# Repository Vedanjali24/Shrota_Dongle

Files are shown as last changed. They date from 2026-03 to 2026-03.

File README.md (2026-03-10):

# Shrota_Dongle
The Shrota Dongle is a custom-designed Ground Control Station (GCS) telemetry interface PCB developed as part of our rocketry team’s avionics and communication system. The board enables reliable reception and processing of real-time telemetry transmitted from the rocket during flight.

The system is built around an STM32 microcontroller, which manages telemetry data handling and communication with a LoRa RYLR module used for long-range wireless data reception. This allows the ground station to receive critical flight parameters and system status during launch and testing.

The PCB features a 5.5 V to 3.3 V regulated power architecture with VCC filtering to ensure stable operation of RF and digital components. High-speed and low-speed oscillators provide precise timing, while external SPI Flash memory allows telemetry data to be logged for redundancy and post-flight analysis.

Developed collaboratively as part of our team’s ground infrastructure, the Shrota Dongle provides a robust communication link for monitoring mission-critical rocket performance.





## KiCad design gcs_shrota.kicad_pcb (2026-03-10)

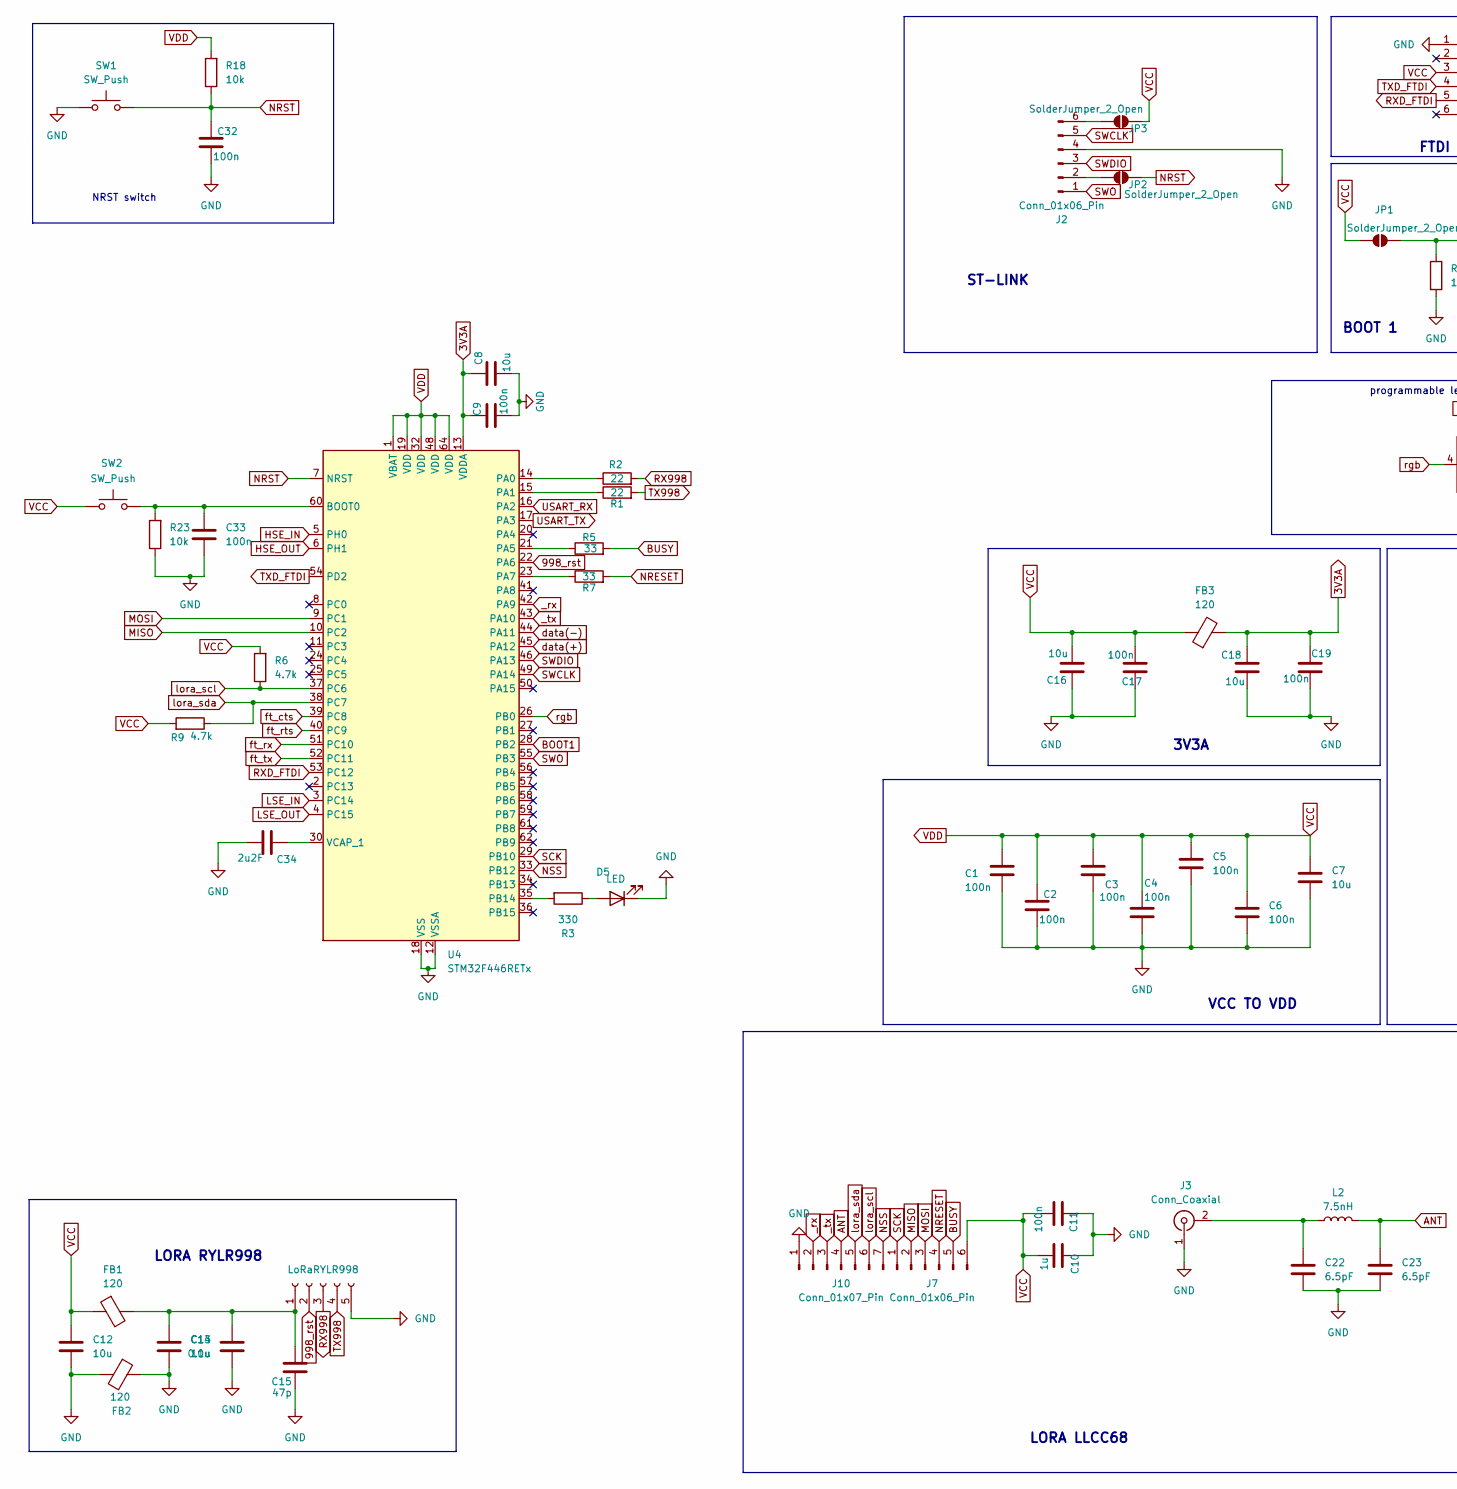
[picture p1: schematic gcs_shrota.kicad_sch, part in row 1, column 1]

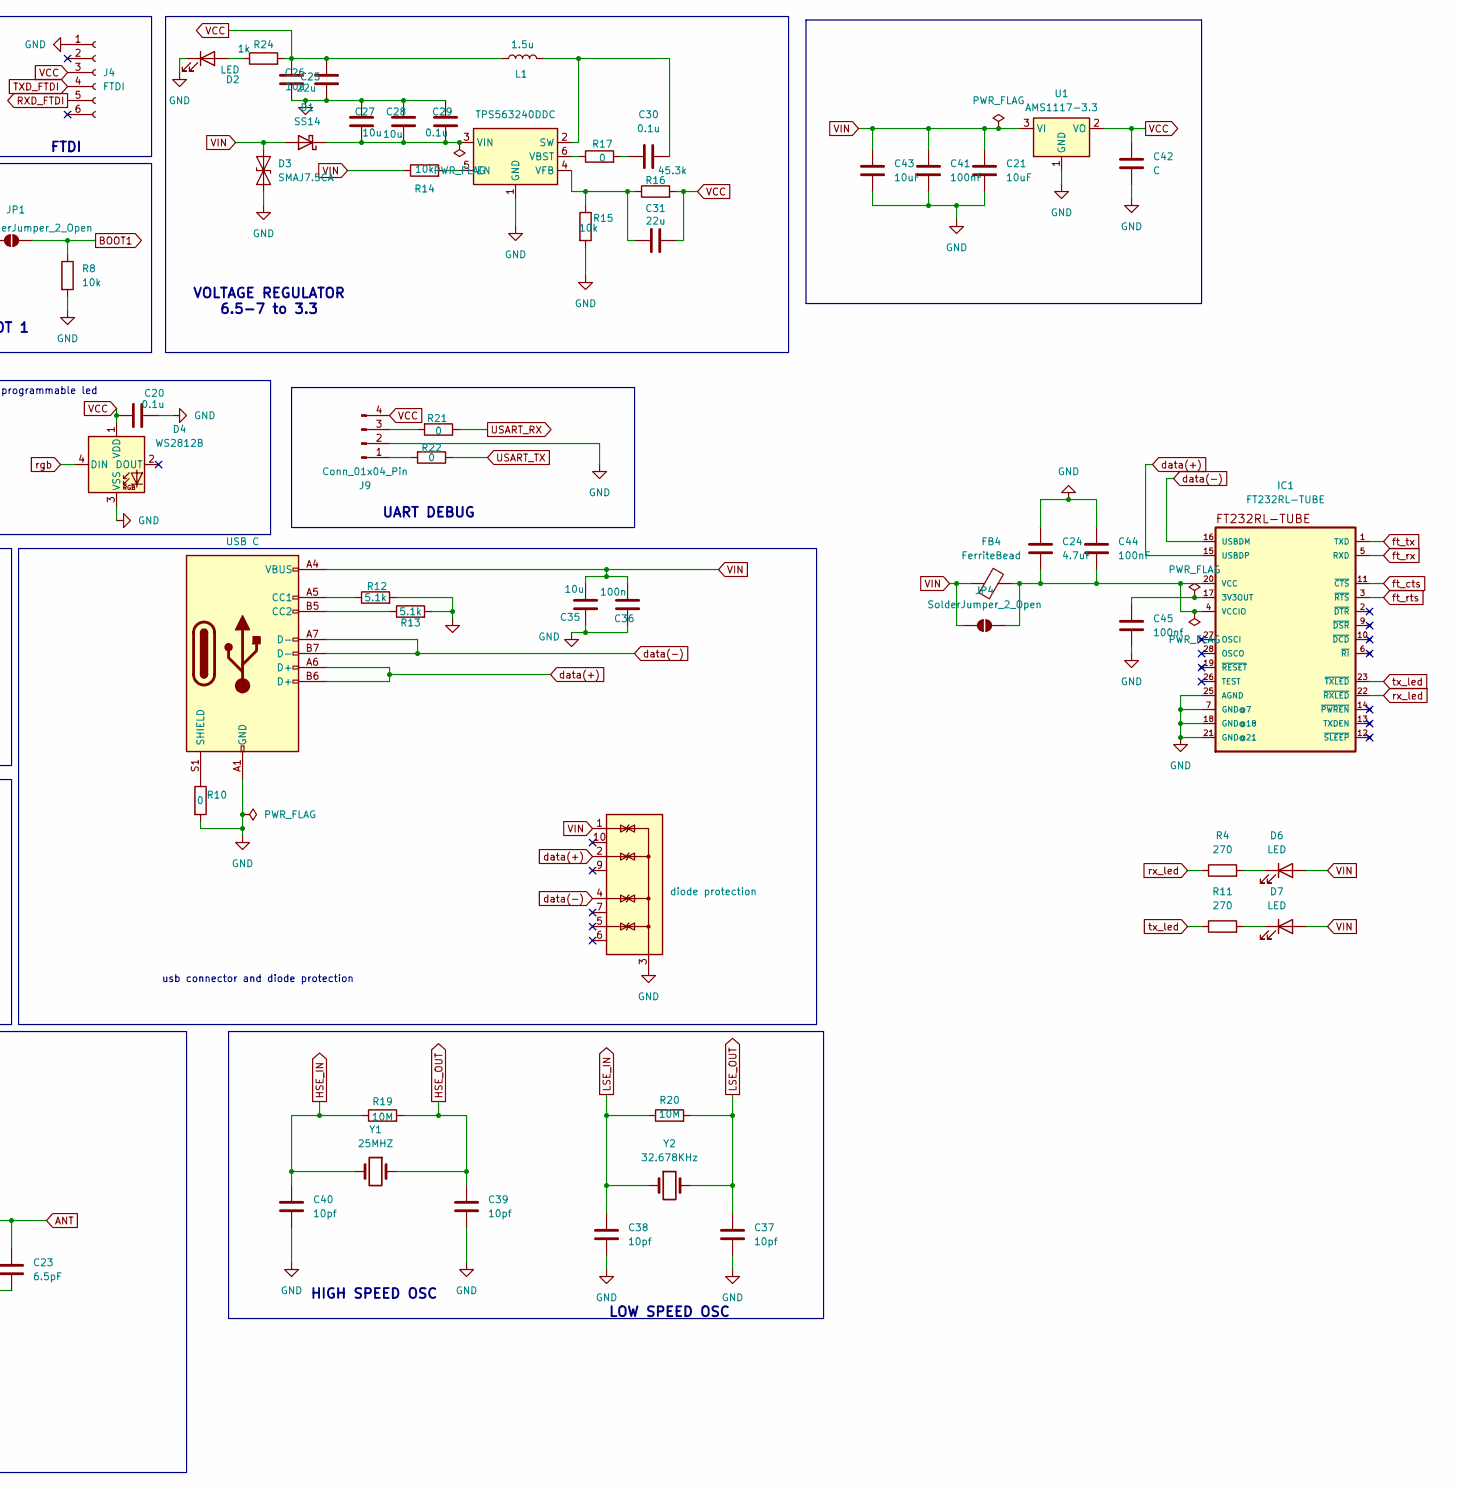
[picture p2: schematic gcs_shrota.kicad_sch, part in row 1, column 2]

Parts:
C1, C2, C3, C4, C5, C6, C9, C11, C17, C19, C32, C33, C36: 100n; C_0603_1608Metric_Pad1.08x0.95mm_HandSolder
C7, C8, C12, C13, C16, C18, C26, C27, C28, C35: 10u; C_0603_1608Metric_Pad1.08x0.95mm_HandSolder
C10: 1u; C_0603_1608Metric_Pad1.08x0.95mm_HandSolder
C14, C20, C29, C30: 0.1u; C_0603_1608Metric_Pad1.08x0.95mm_HandSolder
C15: 47p; C_0603_1608Metric_Pad1.08x0.95mm_HandSolder
C21, C43: 10uF; C_0603_1608Metric_Pad1.08x0.95mm_HandSolder
C22, C23: 6.5pF; C_0603_1608Metric_Pad1.08x0.95mm_HandSolder
C24: 4.7uF; C_0603_1608Metric_Pad1.08x0.95mm_HandSolder
C25, C31: 22u; C_0603_1608Metric_Pad1.08x0.95mm_HandSolder
C34: 2u2F; C_0603_1608Metric_Pad1.08x0.95mm_HandSolder
C37, C38, C39, C40: 10pf; C_0603_1608Metric_Pad1.08x0.95mm_HandSolder
C41, C44: 100nF; C_0603_1608Metric_Pad1.08x0.95mm_HandSolder
C42: C; C_0603_1608Metric_Pad1.08x0.95mm_HandSolder
C45: 100nf; C_0603_1608Metric_Pad1.08x0.95mm_HandSolder
D1: SS14; D_SMA_Handsoldering
D2: LED; LED_0603_1608Metric_Pad1.05x0.95mm_HandSolder
D3: SMAJ7.5CA; D_SMA_Handsoldering
D4: WS2812B; LED_WS2812B_PLCC4_5.0x5.0mm_P3.2mm
D5: LED; D_0603_1608Metric_Pad1.05x0.95mm_HandSolder
D6, D7: LED; C_0603_1608Metric_Pad1.08x0.95mm_HandSolder
FB1, FB2, FB3: 120; L_0603_1608Metric_Pad1.05x0.95mm_HandSolder
FB4: FerriteBead; L_0603_1608Metric_Pad1.05x0.95mm_HandSolder
IC1: FT232RL-TUBE; SSOP28-LD
J1: LoRaRYLR998; PinSocket_1x05_P2.54mm_Vertical
J2, J7: Conn_01x06_Pin; PinHeader_1x06_P2.54mm_Vertical
J3: Conn_Coaxial; SMA_Amphenol_901-144_Vertical
J4: FTDI; PinSocket_1x06_P2.54mm_Vertical
J5: USB C; USB_C_Receptacle_GCT_USB4105-xx-A_16P_TopMnt_Horizontal
J9: Conn_01x04_Pin; PinSocket_1x04_P2.54mm_Vertical
J10: Conn_01x07_Pin; PinHeader_1x07_P2.54mm_Vertical
JP1, JP2, JP3, JP4: SolderJumper_2_Open; SolderJumper-2_P1.3mm_Open_Pad1.0x1.5mm
L1: 1.5u; L_Sunlord_SWPA3015S
L2: 7.5nH; L_0603_1608Metric_Pad1.05x0.95mm_HandSolder
R1, R2: 22; R_0603_1608Metric_Pad0.98x0.95mm_HandSolder
R3: 330; D_0603_1608Metric_Pad1.05x0.95mm_HandSolder
R4, R11: 270; R_0603_1608Metric_Pad0.98x0.95mm_HandSolder
R5, R7: 33; R_0603_1608Metric_Pad0.98x0.95mm_HandSolder
R6, R9: 4.7k; R_0603_1608Metric_Pad0.98x0.95mm_HandSolder
R8, R14, R15, R18, R23: 10k; R_0603_1608Metric_Pad0.98x0.95mm_HandSolder
R10, R17, R21, R22: 0; R_0603_1608Metric_Pad0.98x0.95mm_HandSolder
R12, R13: 5.1k; R_0603_1608Metric_Pad0.98x0.95mm_HandSolder
R16: 45.3k; R_0603_1608Metric_Pad0.98x0.95mm_HandSolder
R19, R20: 10M; R_0603_1608Metric_Pad0.98x0.95mm_HandSolder
R24: 1k; R_0603_1608Metric_Pad0.98x0.95mm_HandSolder
SW1, SW2: SW_Push; SW_PUSH_6mm
U1: AMS1117-3.3; SOT-223-3_TabPin2
U2: diode protection; USON-10_2.5x1.0mm_P0.5mm
U3: TPS563240DDC; SOT-23-6_Handsoldering
U4: STM32F446RETx; LQFP-64_10x10mm_P0.5mm
Y1: 25MHZ; XTAL_ABLS-25.000MHZ-B2F-T
Y2: 32.678KHz; Crystal_SMD_0603-2Pin_6.0x3.5mm

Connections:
3V3A: C8.1, C9.2, C18.1, C19.2, FB3.2, U4.13 (VDDA)
998_rst: J1.2, U4.22 (PA6)
ANT: C23.1, J10.4, L2.2
BOOT1: JP1.2 (B), R8.1, U4.28 (PB2)
BUSY: J7.5, R5.2
GND: C1.2, C2.2, C3.2, C4.2, C5.2, C6.2, C7.2, C8.2, C9.1, C10.2, C11.2, C12.2, C13.2, C14.2, C15.2, C16.1, C17.2, C18.2, C19.1, C20.2, C21.2, C22.2, C23.2, C24.1, C25.2, C26.2, C27.1, C28.1, C29.1, C32.2, C33.2, C34.1, C35.1, C36.2, C37.2, C38.2, C39.2, C40.2, C41.2, C42.2, C43.2, C44.1, C45.2, D2.1 (K), D3.1 (A1), D4.3 (VSS), D5.1 (K), FB2.1, FB2.2, IC1.7 (GND@7), IC1.18 (GND@18), IC1.21 (GND@21), IC1.25 (AGND), J1.5, J2.4, J3.1 (In), J4.1, J5.A1 (GND), J5.A12 (GND), J5.B1 (GND), J5.B12 (GND), J9.2, J10.1, R8.2, R10.2, R12.2, R13.2, R15.2, R23.1, SW1.1, U1.1 (GND), U2.3 (G), U2.8 (G), U3.1 (GND), U4.12 (VSSA), U4.18 (VSS), U4.31 (VSS), U4.47 (VSS), U4.63 (VSS)
HSE_IN: C40.1, R19.1, U4.5 (PH0), Y1.2
HSE_OUT: C39.1, R19.2, U4.6 (PH1), Y1.1
LSE_IN: C38.1, R20.1, U4.3 (PC14), Y2.1
LSE_OUT: C37.1, R20.2, U4.4 (PC15), Y2.2
MISO: J7.2, U4.10 (PC2)
MOSI: J7.3, U4.9 (PC1)
NRESET: J7.4, R7.2
NSS: J10.7, U4.33 (PB12)
unnamed: C30.1, R17.2
unnamed: C27.2, C28.2, C29.2, D1.1 (K), U3.3 (VIN)
unnamed: D2.2 (A), R24.1
unnamed: D5.2 (A), R3.1
unnamed: D6.1 (K), R4.2
unnamed: D7.1 (K), R11.2
unnamed: C45.1, IC1.17 (3V3OUT)
unnamed: C24.2, C44.2, FB4.2, IC1.4 (VCCIO), IC1.20 (VCC), JP4.2 (B)
unnamed: C13.1, C14.1, C15.1, FB1.2, J1.1
unnamed: J2.6, JP3.1 (A)
unnamed: C22.1, J3.2 (Ext), L2.1
unnamed: J5.A5 (CC1), R12.1
unnamed: J5.B5 (CC2), R13.1
unnamed: J5.S1 (SHIELD), R10.1
unnamed: J9.1, R22.2
unnamed: J9.3, R21.2
unnamed: R14.2, U3.5 (EN)
unnamed: C30.2, L1.2, U3.2 (SW)
unnamed: R17.1, U3.6 (VBST)
unnamed: C31.1, R15.1, R16.1, U3.4 (VFB)
unnamed: C33.1, R23.2, SW2.1, U4.60 (BOOT0)
unnamed: R2.1, U4.14 (PA0)
unnamed: R1.1, U4.15 (PA1)
unnamed: R5.1, U4.21 (PA5)
unnamed: R7.1, U4.23 (PA7)
unnamed: R3.2, U4.35 (PB14)
unnamed: C34.2, U4.30 (VCAP_1)
RX998: J1.3, R2.2
RXD_FTDI: J4.5, U4.53 (PC12)
SCK: J7.1, U4.29 (PB10)
SWCLK: J2.5, U4.49 (PA14)
SWDIO: J2.3, U4.46 (PA13)
SWO: J2.1, U4.55 (PB3)
TX998: J1.4, R1.2
TXD_FTDI: J4.4, U4.54 (PD2)
USART_RX: R21.1, U4.16 (PA2)
USART_TX: R22.1, U4.17 (PA3)
VCC: C1.1, C2.1, C3.1, C4.1, C5.1, C6.1, C7.1, C10.1, C11.1, C12.1, C16.2, C17.1, C20.1, C25.1, C26.1, C31.2, C42.1, D4.1 (VDD), FB1.1, FB3.1, J4.3, J7.6, J9.4, JP1.1 (A), JP3.2 (B), L1.1, R6.2, R9.2, R16.2, R18.2, R24.2, SW2.2, U1.2 (VO), U4.1 (VBAT), U4.19 (VDD), U4.32 (VDD), U4.48 (VDD), U4.64 (VDD)
VIN: C21.1, C35.2, C36.1, C41.1, C43.1, D1.2 (A), D3.2 (A2), D6.2 (A), D7.2 (A), FB4.1, J5.A4 (VBUS), J5.A9 (VBUS), J5.B4 (VBUS), J5.B9 (VBUS), JP4.1 (A), R14.1, U1.3 (VI), U2.1 (IO1)
_rx: J10.2, U4.42 (PA9)
_tx: J10.3, U4.43 (PA10)
data(+): IC1.15 (USBDP), J5.A6 (D+), J5.B6 (D+), U2.2 (IO2), U4.45 (PA12)
data(-): IC1.16 (USBDM), J5.A7 (D-), J5.B7 (D-), U2.4 (IO3), U4.44 (PA11)
ft_cts: IC1.11 (~CTS), U4.39 (PC8)
ft_rts: IC1.3 (~RTS), U4.40 (PC9)
ft_rx: IC1.5 (RXD), U4.51 (PC10)
ft_tx: IC1.1 (TXD), U4.52 (PC11)
lora_scl: J10.6, R6.1, U4.37 (PC6)
lora_sda: J10.5, R9.1, U4.38 (PC7)
rgb: D4.4 (DIN), U4.26 (PB0)
rx_led: IC1.22 (~RXLED), R4.1
tx_led: IC1.23 (~TXLED), R11.1

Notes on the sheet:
BOOT 1
VOLTAGE REGULATOR 6.5-7 to 3.3
LORA LLCC68
LOW SPEED OSC
VCC TO VDD
LORA RYLR998
3V3A
NRST switch
FTDI
programmable led
ST-LINK
UART DEBUG
usb connector and diode protection
HIGH SPEED OSC

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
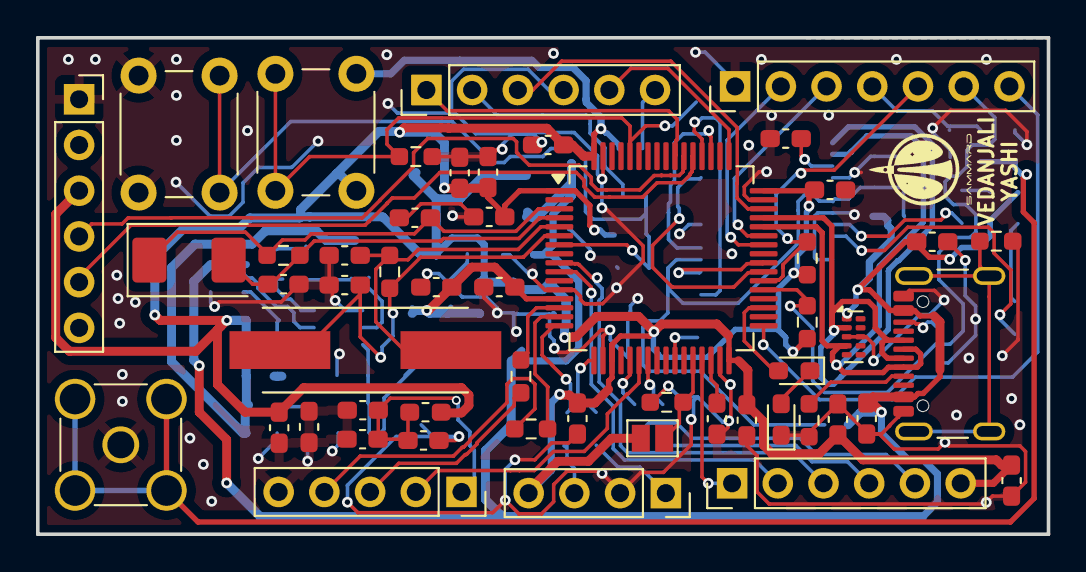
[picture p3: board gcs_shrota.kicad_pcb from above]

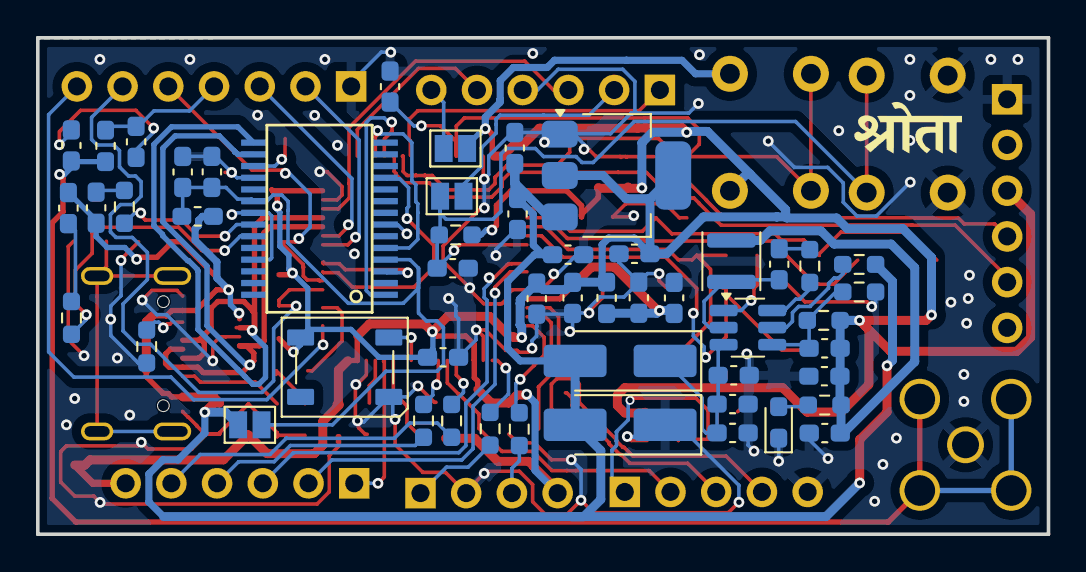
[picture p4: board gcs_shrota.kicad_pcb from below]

Board: 2 copper layers, 56.1 x 27.6 mm, 103 parts (51 on the bottom side), 68 nets.
